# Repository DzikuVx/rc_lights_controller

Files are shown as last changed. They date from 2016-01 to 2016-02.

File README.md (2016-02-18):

#RC Lights Controller

Lights controller for RC planes, drones, quadcopters driven by RC PWM signal

## Hardware

* ATtiny85 uC
* Transistor BC337-40 or compatible x2
* Transistor BD139-16 or compatible
* 3.3 kOhm resistor
* 470 Ohm resistor
* Some kind of PCB, universal for example
* DuPont 2.54mm male connectors
* TACT switch

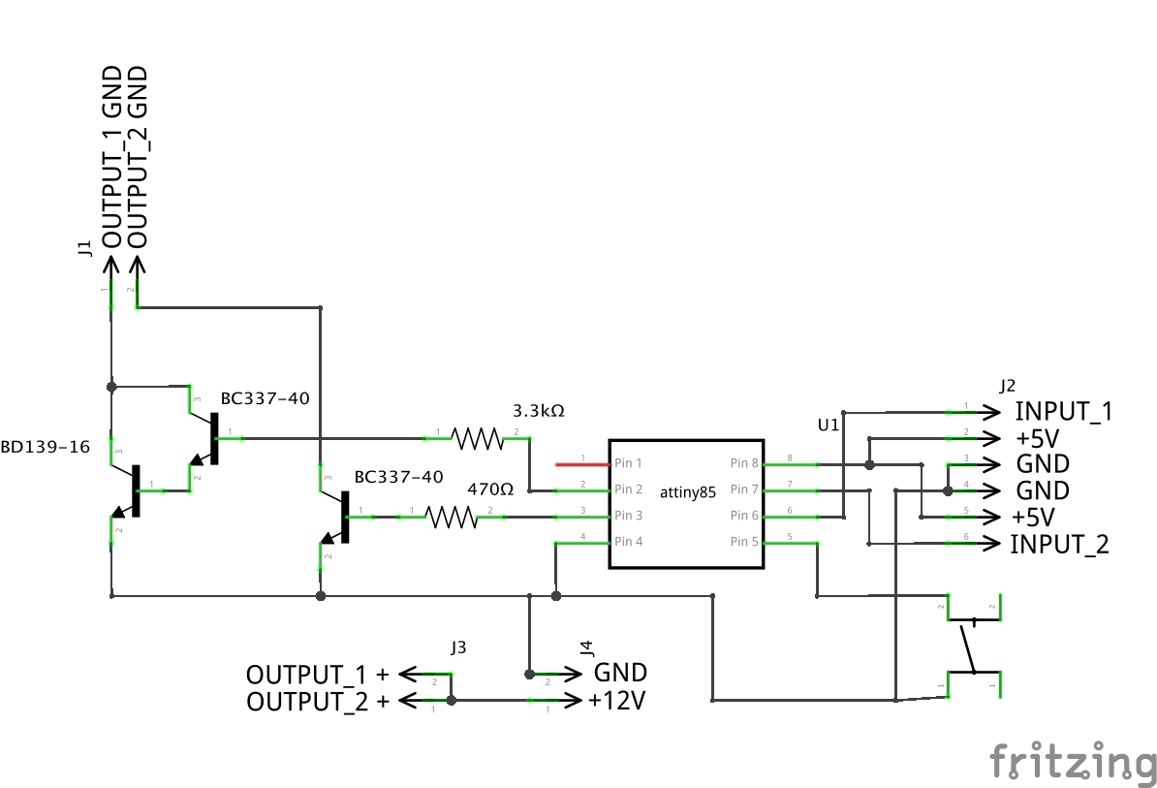
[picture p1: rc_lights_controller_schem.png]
schema

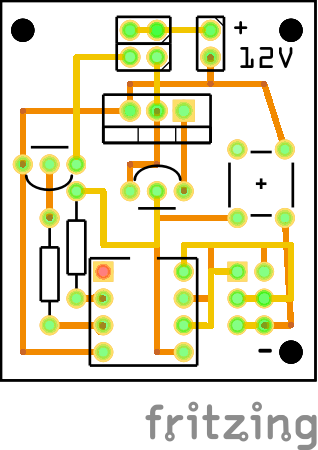
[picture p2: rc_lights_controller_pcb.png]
PCB view


PCB files (Gerber format) ready for production are in PCB folder. Test batch ordered from [OSH Park](https://oshpark.com/) was perfect, ready to solder!

### Programming ATtiny85

* Arduino IDE 1.6.6. Should work on older releases, but never tested
* ATtiny45/85 board definitions. Tested with [damellis/attiny](https://github.com/damellis/attiny)
* Uses 8MHz internal osciallator 
* You will need ISP programmer to program ATtiny. I use USBasp. Works perfectly under Linux, Windows and Mac OS X.
* Tutorial how to flash ATtiny can be found [here](https://quadmeup.shtr.eu/programming-attiny85-and-attiny45-with-arduino-ide/)

##Input modes

***RC Lights Controller*** can work in following modes:

* ***No RC input*** - in this mode, light pattern is set by pressing a button. There are 6 preprogrammed patterns that can be used without PWM input. Selected mode is stored in EEPROM memory and will be automatically selected on next power up,
* ***Single RC PWM input*** - in this mode, lights pattern is determined by RC signal on INPUT_1. 2 and 3 position switches are supported. By default:
    * with 2 position switch *RC Lights Controller* works like on-off switch for OUTPUT_1. OUTPUT_2 is not used
    * with 3 position switch, OUTPUT_1 works as: OFF, BLINK, ON. OUTPUT_2 is not used  
* ***Two RC inputs*** - in this mode, total of 9 light modes can be selected using two 3 position switches. Two 2 position switches allows to choose one from 4 light modes. By default:
    * ***INPUT_1*** works like master switch providing the same "modes" like in ***Single RC PWM Input***
    * ***INPUT_2*** works like subprogram selector 
    * ***OUTPUT_2*** is enabled only when ***INPUT_1*** is in ***HIGH*** state
    
## Output max load

* OUTPUT_1
    * This is high current output that should work up 1A of load. Remember that power transistor will heat up, so at one point it will require an radiator,
    * On 12V and 400mA power it is already 4.8W load, and max for this transistor is 8W. Be careful 
    * In theory this output can handle up to 80V, but I recommend not to go above 25V. This is already 6S battery, you really need more? 
* OUTPUT_2
    * This is low current output that should not be used above 250mA of load.
    * In theory it can accept up to 45V, but it was rather designed to use buzzer or something with similar requirements. So 12V is a real - life limit here 

In case of both outputs, it is most reasonable to use 12V on both.
    
## Output Modes

Those are default values. They can be modified in code using _patterns_ array. Each number in this array represents cycle number in which output channes should change: from LOW to HIGH, or from HIGH to LOW. Cycle takes 100ms. So, combination of: ```{10, 20, 30, 40, 50, 60, 70, 80}``` means: turn channel ON on cycle 10, turn it OFF on cycle 20, turn it ON on cycle 30 and so on.  

### OUTPUT_1
    
| | INPUT_2 LOW or not connected  | INPUT_2 MID | INPUT_2 HIGH  | 
|--- |--- |--- |--- |
| ***INPUT_1 LOW*** | OFF | OFF | OFF |
| ***INPUT_1 MID*** | BLINK 1 | BLINK 2 | BLINK 3 |
| ***INPUT_1 HIGH***  | ON | ON | OFF |

### OUTPUT_2

| | INPUT_2 LOW or not connected  | INPUT_2 MID | INPUT_2 HIGH  | 
|--- |--- |--- |--- |
| ***INPUT_1 LOW*** | OFF | OFF | OFF |
| ***INPUT_1 MID*** | OFF | OFF | OFF |
| ***INPUT_1 HIGH***  | ON | OFF | ON |

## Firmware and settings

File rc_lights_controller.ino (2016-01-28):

#include <EEPROM.h>
#include <PinChangeInterrupt.h>

#define OUTPUT_CHANNELS 2
#define LPF_FACTOR 0.8
#define MAX_TICK 127
#define CHANGES_PER_CHANNEL 8
#define CYCLE_OFF 255
#define CYCLE_ON 0
#define BUTTON_PIN 0
#define EEPROM_BUTTON_MODE_ADDRESS 0

/*
 * Define pins used to provide RC PWM signal to Arduino
 * Pins 8, 9 are used since they work on both ATMega328 and 
 * ATMega32u4 board. So this code will work on Uno/Mini/Nano/Micro/Leonardo
 * See PinChangeInterrupt documentation for usable pins on other boards
 */
const byte channel_pin[OUTPUT_CHANNELS] = {2, 1};
volatile unsigned long rising_start[OUTPUT_CHANNELS] = {0, 0};
volatile unsigned int channel_length[OUTPUT_CHANNELS] = {0, 0};

const byte output_pin[OUTPUT_CHANNELS] = {3, 4};

/*
 * Do not use 0 or values above MAX_TICK
 * 255 no light never
 */
const byte patterns[9][OUTPUT_CHANNELS][CHANGES_PER_CHANNEL] = {
  {{CYCLE_OFF}, {CYCLE_OFF}}, //CH1 LOW, CH2 LOW or not connected
  {{9, 10, 19, 20, 29, 30, 39, 40}, {CYCLE_OFF}}, //CH1 MID, CH2 LOW or not connected
  {{CYCLE_ON}, {CYCLE_ON}}, //CH1 HIGH, CH2 LOW or not connected
  {{CYCLE_OFF}, {CYCLE_OFF}}, //CH1 LOW, CH2 MID
  {{5, 10, 15, 20, 25, 30, 35, 40}, {CYCLE_OFF}}, //CH1 MID, CH2 MID
  {{CYCLE_ON}, {CYCLE_OFF}}, //CH1 HIGH, CH2 MID
  {{CYCLE_OFF}, {CYCLE_OFF}}, //CH1 LOW, CH2 HIGH
  {{20,21,22,23,43,44,45,46}, {CYCLE_OFF}}, //CH1 MID, CH2 HIGH
  {{CYCLE_OFF}, {CYCLE_ON}} //CH1 HIGH, CH2 HIGH
};

const byte buttonModes[6] = {0, 1, 4, 7, 5, 8};
byte buttonMode = 0;
byte previousButtonState = HIGH;
byte currentButtonState = LOW;

void setup() {

  /*
   * read stored button mode from EEPROM
   */
  buttonMode = EEPROM.read(EEPROM_BUTTON_MODE_ADDRESS);
  if (buttonMode >= sizeof(buttonModes)) {
    buttonMode = 0;  
  }

  pinMode(channel_pin[0], INPUT);
  pinMode(channel_pin[1], INPUT);
  pinMode(BUTTON_PIN, INPUT_PULLUP);

  pinMode(output_pin[0], OUTPUT);
  pinMode(output_pin[1], OUTPUT);
  pinMode(output_pin[2], OUTPUT);

  attachPinChangeInterrupt(channel_pin[0], onRising0, CHANGE);
  attachPinChangeInterrupt(channel_pin[1], onRising1, CHANGE);
}

int smooth(int data, float filterVal, float smoothedVal){

  if (filterVal > 1){ // check to make sure params are within range
    filterVal = .99;
  }
  else if (filterVal <= 0){
    filterVal = 0;
  }

  smoothedVal = (data * (1 - filterVal)) + (smoothedVal  *  filterVal);

  return (int)smoothedVal;
}

void processPin(byte pin) {
  uint8_t trigger = getPinChangeInterruptTrigger(channel_pin[pin]);

  if(trigger == RISING) {
    rising_start[pin] = micros();
  } else if(trigger == FALLING) {
    unsigned int val = micros() - rising_start[pin];
    channel_length[pin] = smooth(val, LPF_FACTOR, channel_length[pin]);
  }
}

void onRising0(void) {
  processPin(0);
}

void onRising1(void) {
  processPin(1);
}

bool rcModeEnabled = false;

byte output_table[3] = {false, false, false};

byte pattern = 0;
byte patternPrevious = 0;
byte patternIndex[OUTPUT_CHANNELS] = {0, 0};

unsigned long tick[OUTPUT_CHANNELS] = {0, 0};

int currentPattern = 0;

void resetOutput() {

  for (int i = 0; i < OUTPUT_CHANNELS; i++) {
    output_table[i] = false;
    tick[i] = 0;
    patternIndex[i] = 0;
  }
}

byte channelLengthToPosition(unsigned int channelLength) {

  if (channelLength < 1250 || channelLength > 2400) {
    return 0;
  } else if (channelLength < 1750) {
    return 1;
  } else {
    return 2;
  }
  
}

void loop() {

  if (channel_length[0] > 600 && channel_length[0] < 2400) {
    rcModeEnabled = true;
  } else {
    rcModeEnabled = false;
  }

  if (rcModeEnabled) {
    pattern = (3 * channelLengthToPosition(channel_length[1])) + channelLengthToPosition(channel_length[0]);
  } else {
    pattern = buttonModes[buttonMode];
  }
  if (pattern != patternPrevious) {
    resetOutput();
  }

  for (byte i = 0; i < OUTPUT_CHANNELS; i++) {
    currentPattern = patterns[pattern][i][patternIndex[i]];

    if (currentPattern == CYCLE_ON) {
      output_table[i] = true;
    } else if (tick[i] == currentPattern) {
      patternIndex[i]++;    
      output_table[i] = !output_table[i];
    }

    tick[i]++;

    if (patternIndex[i] == CHANGES_PER_CHANNEL) {
      tick[i] = 0;
      patternIndex[i] = 0;
    }

    if (tick[i] == MAX_TICK) {
      tick[i] = 0;
      patternIndex[i] = 0;
    }
  }

  if (!rcModeEnabled) {

    currentButtonState = digitalRead(BUTTON_PIN);

    if (currentButtonState == LOW && previousButtonState == HIGH) {
      buttonMode++;
      if (buttonMode >= sizeof(buttonModes)) {
        buttonMode = 0;
      }
      /*
       * Also, save current mode to EEPROM
       * Let's assume that few thousad writes is safe in this case. Like 100,000 ? A lot!
       */
       EEPROM.write(EEPROM_BUTTON_MODE_ADDRESS, buttonMode);
    }
    previousButtonState = currentButtonState;
  }

  patternPrevious = pattern;

  for (int i = 0; i < OUTPUT_CHANNELS; i++) {
    digitalWrite(output_pin[i], (byte) output_table[i]);
  }
  
  delay(100);
}

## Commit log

2016-01-05 interrupt processing improvements
2016-01-26 button driven mode when no RC input is available
    [rc_lights_controller.fzz]
2016-01-27 readme update
    [rc_lights_controller.fzz]
2016-01-28 ATtiny85 compatibility
    [rc_lights_controller.fzz]
2016-01-29 PCB view
    [rc_lights_controller.fzz]
